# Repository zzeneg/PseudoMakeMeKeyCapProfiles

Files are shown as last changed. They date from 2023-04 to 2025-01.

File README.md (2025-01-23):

# Pseudo Make Me Key Cap Profile

## Added by zzeneg

#### DES MX

Compatible with **KS-33** (Gateron Lop Profile), **Choc V2**, **MX** and **mid-MX** (Tecsee Medium)

- [low profile version](./stl/MX-LP) - shorter skirt for low profile compatibility
- [minY minZ version](./stl/MX-minY-minZ) - 19x16mm spacing and reduced height, additional keycaps for edges (tilted inside)

#### DES Choc v1

- [minY version](./stl/Choc-minY) - 19x16mm spacing, additional keycaps for edges (tilted inside)

> [!WARNING]
> All versions are tested in MJF Nylon from JLCPCB only, be careful with other materials/manufacturers, make a small test order if possible.

## What the fork

- scripts to generate CS, DES, and Liminal Chimera keycaps
- sprued stls packs for MJF/SLS printing
- adding 1.25 to 2.25u Choc CS regular and convex caps

## How to

- make sure OpenSCAD is up to date.
- unzip libraries.zip into your OpenSCAD libraries
- select keycap you want to render by changing KeyID value
- change KeyID to corresponding Parameter ID
- press F5 to review
- press F6 to render
- press F7 to export as STL

#Some notes on

## Distorted Ellipsoidal Saddle (DES)

High sculpt smooth transition profile
DES

### Standard

Neuron v1

### Concave

Corne thumb and Convex Caps

### Thumbs

IMK Corne v1
Kyria

### Chicago Stenographer

Subtly sculpted choc spaced low profile
CS

#### Standard

Look

#### Convex

Georgi

#### Thumbs

1.5 + 1
Additional sculpt angle and smoother transitions

### Philadelphia Minimalist

under
Minimal spacing
Under construction

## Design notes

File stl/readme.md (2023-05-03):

Note
======

### Chicago Steno
- 1u sets have been printed in MJF by JLCPCB once with excellent results.
- thumbs are asymmetrical. Each set contains three pairs.
- 1.25~2.25u keys were modified by me and have not tested

### DES, Liminal Chimera
* MX stems are generated with `Tol=0.0`, tested once with good results in SLS. Not sure about resin.

Proceed with caution.

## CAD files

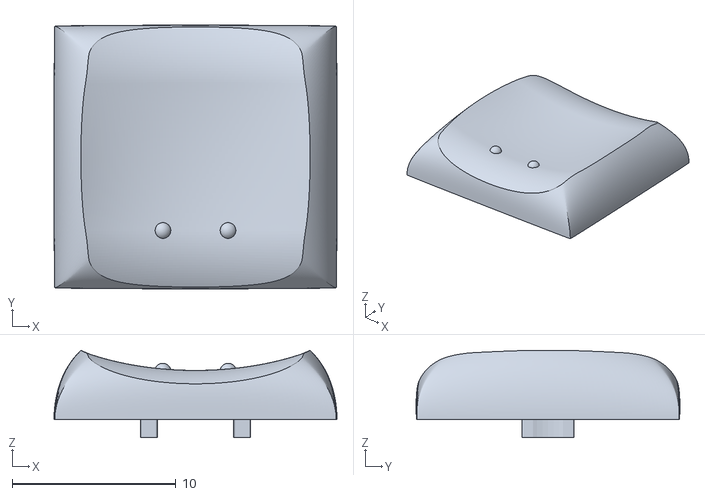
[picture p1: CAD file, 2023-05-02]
stl/Choc/Chicago_Steno_R3_homedot.stl
17.3 x 16.1 x 5.35

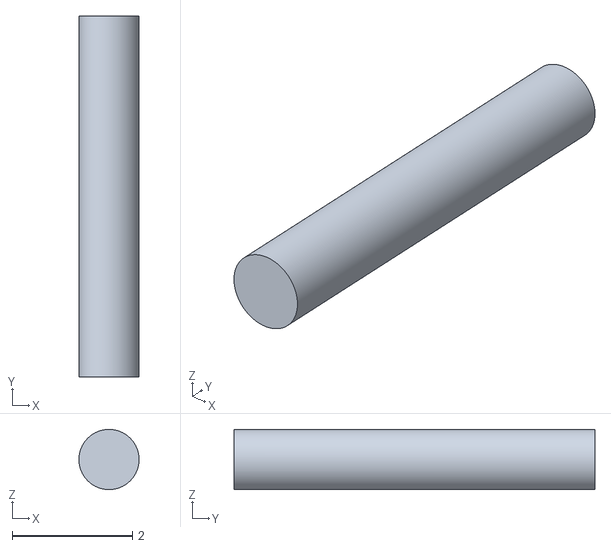
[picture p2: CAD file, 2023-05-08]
stl/MX/DES_r5_convex_1.50u_x2.stl
1.00 x 6.00 x 1.00

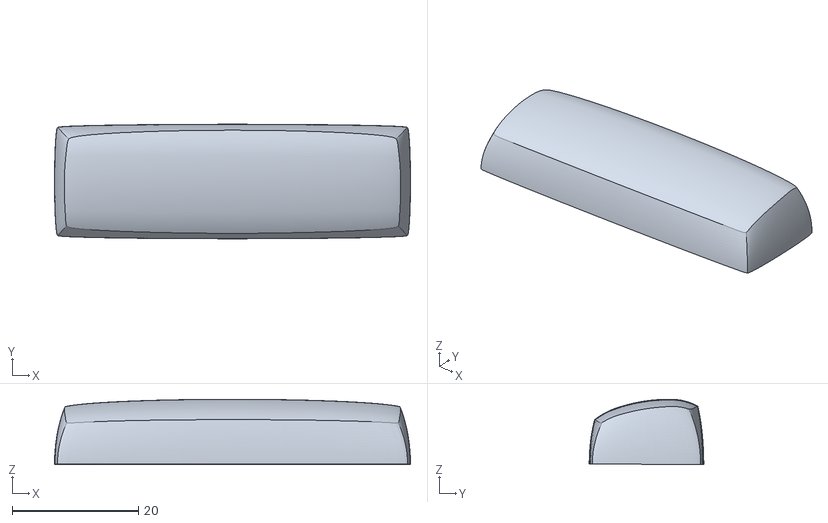
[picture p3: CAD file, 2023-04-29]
stl/MX/DES_r5_convex_3u.stl
56.3 x 18.1 x 10.4

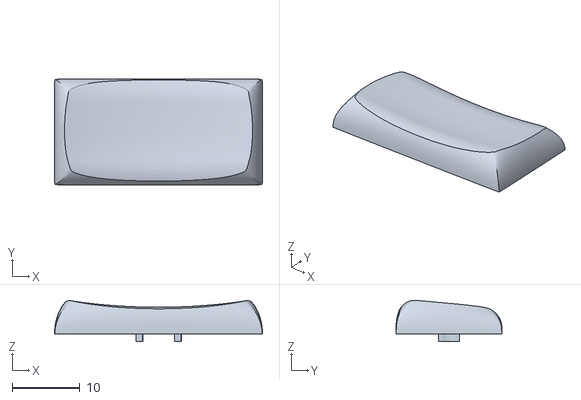
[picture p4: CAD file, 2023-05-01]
stl/Choc/Chicago_Steno_R2_1.75u.stl
30.8 x 15.7 x 6.08

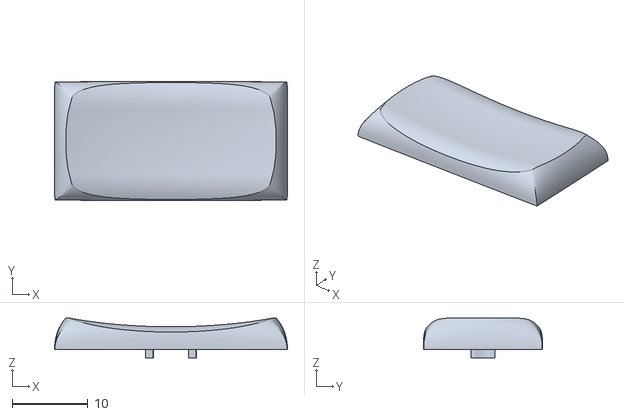
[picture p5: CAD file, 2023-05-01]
stl/Choc/Chicago_Steno_R3_1.75u.stl
30.8 x 15.7 x 5.26

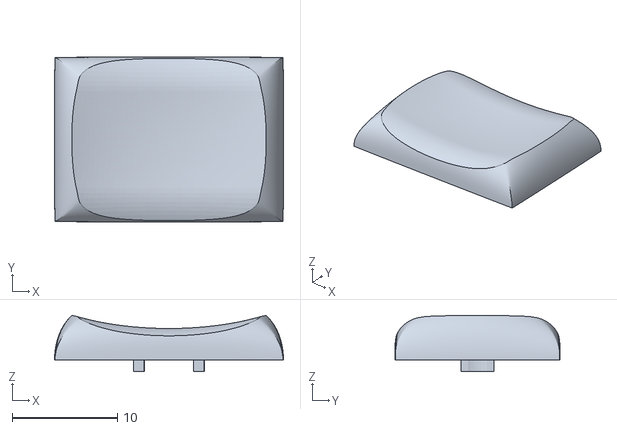
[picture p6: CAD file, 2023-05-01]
stl/Choc/Chicago_Steno_R3_1.25u.stl
21.8 x 15.7 x 5.37

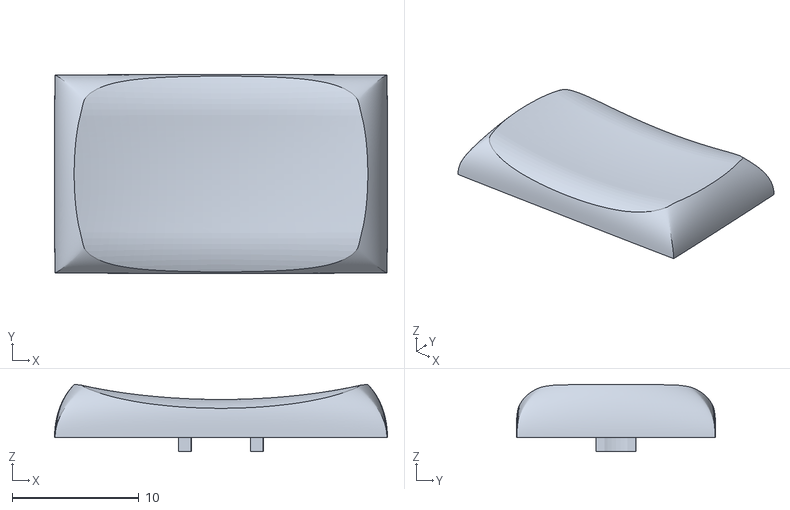
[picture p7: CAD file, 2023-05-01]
stl/Choc/Chicago_Steno_R3_1.50u.stl
26.3 x 15.7 x 5.30

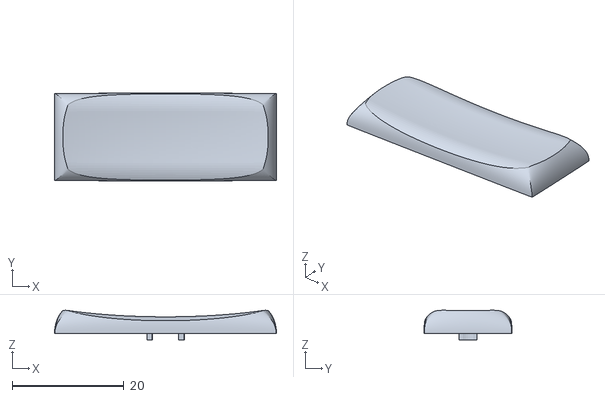
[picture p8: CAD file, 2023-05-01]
stl/Choc/Chicago_Steno_R3_2.25u.stl
39.8 x 15.7 x 5.30

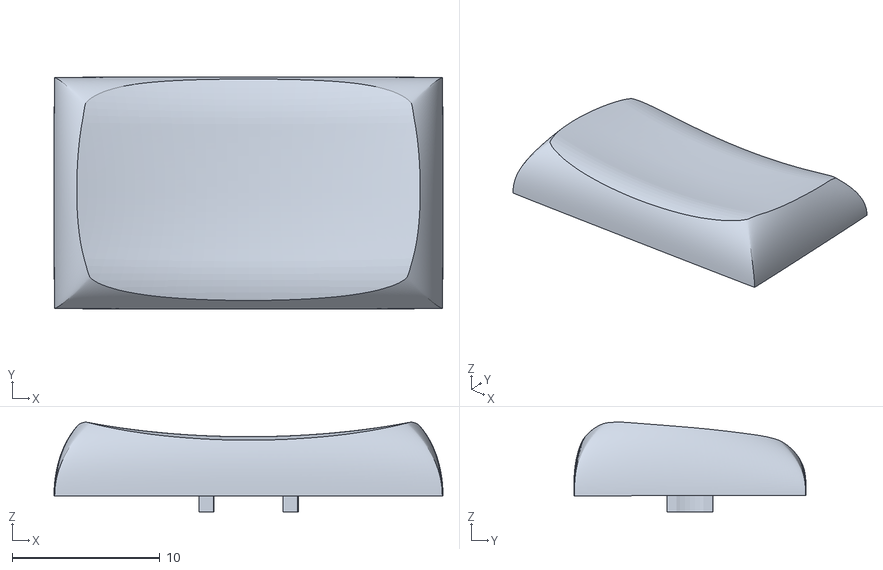
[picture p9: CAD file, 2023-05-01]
stl/Choc/Chicago_Steno_R2_1.50u.stl
26.3 x 15.7 x 6.07

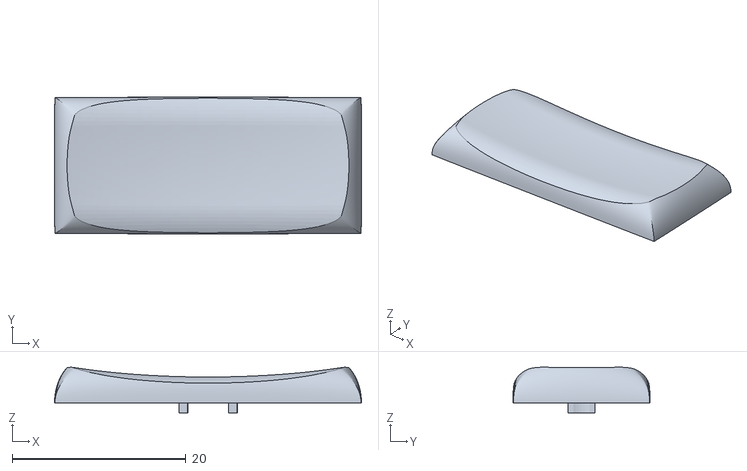
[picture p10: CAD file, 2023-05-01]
stl/Choc/Chicago_Steno_R3_2.00u.stl
35.3 x 15.7 x 5.25

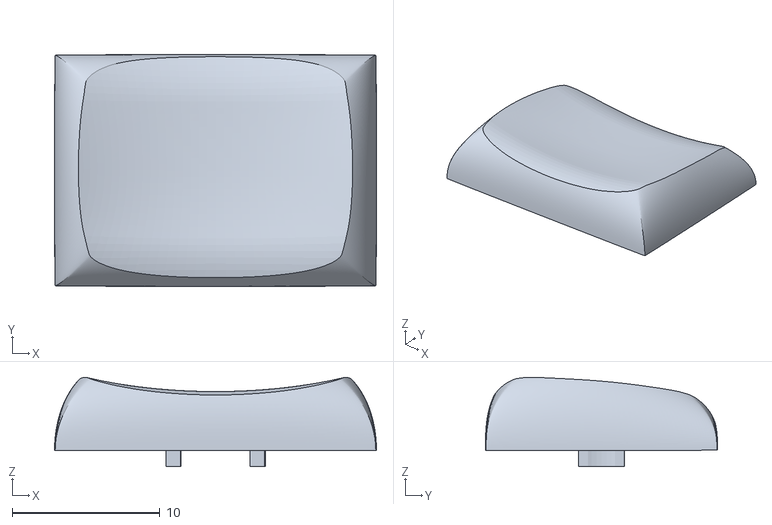
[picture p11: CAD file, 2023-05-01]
stl/Choc/Chicago_Steno_R2_1.25u.stl
21.8 x 15.7 x 6.05

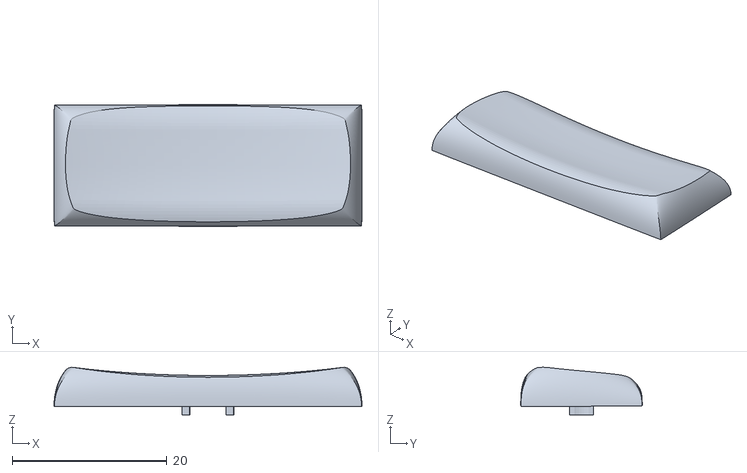
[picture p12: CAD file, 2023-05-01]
stl/Choc/Chicago_Steno_R2_2.25u.stl
39.8 x 15.7 x 6.15

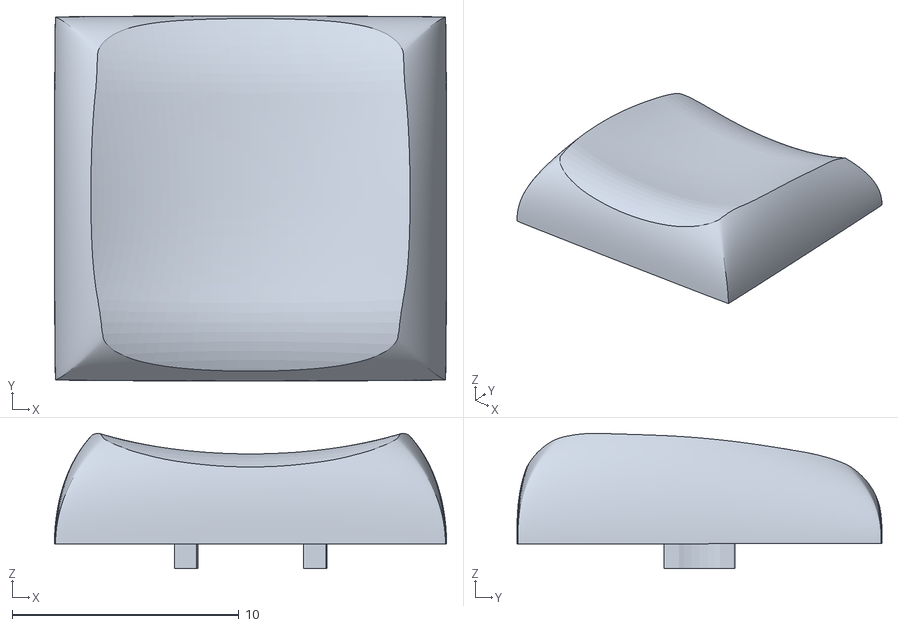
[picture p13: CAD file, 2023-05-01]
stl/Choc/Chicago_Steno_R2_1.00u.stl
17.3 x 16.1 x 5.97

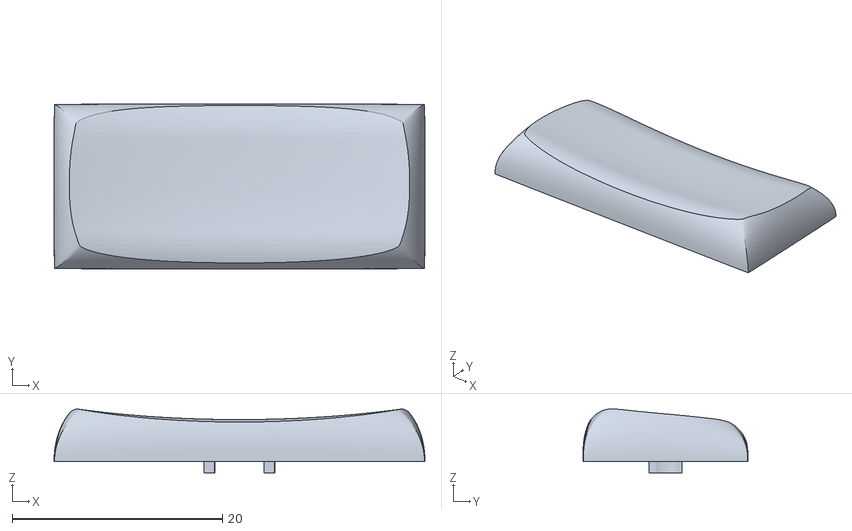
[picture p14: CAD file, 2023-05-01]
stl/Choc/Chicago_Steno_R2_2.00u.stl
35.3 x 15.7 x 6.09

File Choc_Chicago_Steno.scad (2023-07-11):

use <./libraries/scad-utils/morphology.scad> //for cheaper minwoski
use <./libraries/scad-utils/transformations.scad>
use <./libraries/scad-utils/shapes.scad>
use <./libraries/scad-utils/trajectory.scad>
use <./libraries/scad-utils/trajectory_path.scad>
use <./libraries/sweep.scad>
use <./libraries/skin.scad>
//use <z-butt.scad>

//Choc Chord version Chicago Stenographer

/*Tester */
keycap(
  keyID  = 6, //change profile refer to KeyParameters Struct
  cutLen = 0, //Don't change. for chopped caps
  Stem   = true, //tusn on shell and stems
  StemRot = 0, //change stem orientation by deg
  Dish   = true, //turn on dish cut
  Stab   = 0,
  visualizeDish = false, // turn on debug visual of Dish
  crossSection  = false, // center cut to check internal
  homeDot = false, //turn on homedots,
  homeBar = true, //turn on homebar,
  Legends = false
  );

//-Parameters
wallthickness = 1.1; // 1.75 for mx size, 1.1
topthickness = 3.0; //2 for phat 3 for chicago
stepsize = 50;  //resolution of Trajectory
step = 0.5;       //resolution of ellipes
fn = 60;          //resolution of Rounded Rectangles: 60 for output
layers = 50;    //resolution of vertical Sweep: 50 for output

//---Stem param
slop    = 0.3;
stemRot = 0;
stemWid = 8;
stemLen = 6;
stemCrossHeight = 1.8;
extra_vertical = 0.6;
stemLayers = 50; //resolution of stem to cap top transition
//#cube([18.16, 18.16, 10], center = true); // sanity check border

//injection param
draftAngle = 0; //degree  note:Stem Only
//TODO: Add wall thickness transition?


keyParameters = //keyParameters[KeyID][ParameterID]
[
//  BotWid, BotLen, TWDif, TLDif, keyh, WSft, LSft  XSkew, YSkew, ZSkew, WEx, LEx, CapR0i, CapR0f, CapR1i, CapR1f, CapREx, StemEx
    //Column 0
    //Levee: Chicago in choc Dimension
    [17.20,  16.00,   5.6, 	   5,  4.9,    0,   .0,     5,    -0,    -0,   2, 2.5,    .10,      2,     .10,      3,     2,       2], //Chicago Steno R2/R4
    [17.20,  16.00,   5.6, 	   5,  4.5,    0,   .0,     0,    -0,    -0,   2, 2.5,    .10,      3,     .10,      3,     2,       2], //Chicago Steno R3 flat
    [17.20,  16.00,  1.25, 	1.25,  4.5,    0,   .0,     0,    -0,    -0,   2, 2.5,    .10,     .5,     .10,     .5,     2,       2], //Chicago Steno R3 chord
    //mods 3
    [17.20,  16.00,  4.25, 	3.25,  5.5,  -.7,  0.7,     0,    -4,    -0,   2,   2,    .10,      2,     .10,      2,     2,       2], //Levee Corner R2
    [17.20,  16.00,  4.25, 	3.25,  5.2,  -.8,  0.6,     0,    -4,    -0,   2,   3,    .10,      2,     .10,      2,     2,       2], //Levee Corner R2
    //1.25: [5, 6]
    [21.7,   15.60,  5.6, 	   5,  4.9,    0,   .0,     5,    -0,    -0,   2, 2.5,     .1,      2,      .1,      3,     2,       2], //Chicago Steno R2/R4 1.25u
    [21.7,   15.60,  5.6, 	   5,  4.5,    0,   .0,     0,    -0,    -0,   2, 2.5,     .1,      3,      .1,      3,     2,       2], //Chicago Steno R3 1.25u
    //1.5: [7, 8]
    [26.20,  15.60,   5.6, 	   5,  4.9,    0,   .0,     5,    -0,    -0,   2, 2.5,     .1,      2,      .1,      3,     2,       2], //Chicago Steno R2/R4 1.5
    [26.20,  15.60,   5.6, 	   5,  4.5,    0,   .0,     0,    -0,    -0,   2, 2.5,     .1,      3,      .1,      3,     2,       2], //Chicago Steno R3 1.5u
    //1.75: [9, 10]
    [30.70,  15.60,   5.6, 	   5,  4.9,    0,   .0,     5,    -0,    -0,   2, 2.5,     .1,      2,      .1,      3,     2,       2], //Chicago Steno R2/R4 1.5
    [30.70,  15.60,   5.6, 	   5,  4.5,    0,   .0,     0,    -0,    -0,   2, 2.5,     .1,      3,      .1,      3,     2,       2], //Chicago Steno R3 1.5u
    //2.00: [11, 12]
    [35.20,  15.60,   5.6, 	   5,  4.9,    0,   .0,     5,    -0,    -0,   2, 2.5,     .1,      2,      .1,      3,     2,       2], //Chicago Steno R2/R4 1.5
    [35.20,  15.60,   5.6, 	   5,  4.5,    0,   .0,     0,    -0,    -0,   2, 2.5,     .1,      3,      .1,      3,     2,       2], //Chicago Steno R3 1.5u
    //2.25: [13, 14]
    [39.70,  15.60,   5.6, 	   5,  4.9,    0,   .0,     5,    -0,    -0,   2, 2.5,     .1,      2,      .1,      3,     2,       2], //Chicago Steno R2/R4 1.5
    [39.70,  15.60,   5.6, 	   5,  4.5,    0,   .0,     0,    -0,    -0,   2, 2.5,     .1,      3,      .1,      3,     2,       2], //Chicago Steno R3 1.5u
    // Ergo shits
    [18.75,  18.75,   5.6, 	   5,    8,    0,   .25,     0,    -0,    -0,   2, 2.5,    .10,      3,     .10,      3,     2,       2], //highpro 19.05 R2|4
    [17.20,  16.00,   5.6, 	   5,  4.7,    0,   .0,      3,    -0,    -0,   2, 2.5,    .10,      2,     .10,      3,     2,       2], //Chicago Steno R2 ALT
    [17.20,  16.00,   5.6, 	   5,  5.5,    0,   .0,      7,    -0,    -0,   2, 2.5,    .10,      2,     .10,      3,     2,       2], //Chicago Steno R1 Steap
    [17.20,  16.00,   5.6, 	   5,  7.0,    0,   .0,     10,    -0,    -0,   2, 2.5,    .10,      2,     .10,      3,     2,       2] //Chicago Steno R1 mild with alt R2
];

dishParameters = //dishParameter[keyID][ParameterID]
[
//FFwd1 FFwd2 FPit1 FPit2  DshDep DshHDif FArcIn FArcFn FArcEx     BFwd1 BFwd2 BPit1 BPit2  BArcIn BArcFn BArcEx
  //Column 0
  [ 4.5,    4,    7,  -50,      7,    1.7,   11.5,    17.5,     2,      4.5,    4,    2,   -35,   11.5,  15,     2], //Chicago Steno R2/R4
  [ 4.5,    4,    5,  -40,      7,    1.7,   11.5,    15,     2,      4.5,    4,    5,   -40,   11.5,    15,     2], //Chicago Steno R3 flat
  [ 4.5,    4,    5,  -40,      7,    1.7,   11.5,    15,     2,      4.5,    4,    5,   -40,   11.5,    15,     2], //Chicago Steno R3 chord

  [   6,  3.5,    7,  -50,      5,    1.0,   16,    23,     2,        6,  3.5,    7,   -50,   16,    23,     2], //Levee Steno R2/R4
  [   6,  3.5,    7,  -50,      5,    1.0,   16,    23,     2,        6,  3.5,    7,   -50,   16,    23,     2], //Levee Steno R2/R4
  //1.25
  [ 4.5,    4,    7,  -40,      8,    1.7,   16.0,  22.5,     2,      4.5,    4,    2,   -35,   16.0,  19.5,     2], //Chicago Steno R2/R4
  [ 4.5,    4,    5,  -40,      8,    1.7,   16.0,  19.5,     2,      4.5,    4,    5,   -40,   16.0,  19.5,     2], //Chicago Steno R3
  //1.5
  [ 4.5,    4,    7,  -40,      8,    1.7,   20.5,  26.5,     2,      4.5,    4,    2,   -35,   20.5,  24.0,     2], //Chicago Steno R2/R4
  [ 4.5,    4,    5,  -40,      8,    1.7,   20.5,  24.0,     2,      4.5,    4,    5,   -40,   20.5,  24.0,     2], //Chicago Steno R3
  //1.75
  [ 4.5,    4,    7,  -40,      8,    1.7,   25.0,  31.0,     2,      4.5,    4,    2,   -35,   25.0,  28.5,     2], //Chicago Steno R2/R4
  [ 4.5,    4,    5,  -40,      8,    1.7,   25.0,  28.5,     2,      4.5,    4,    5,   -40,   25.0,  28.5,     2], //Chicago Steno R3
  //2.00
  [ 4.5,    4,    7,  -40,      8,    1.7,   29.5,  35.5,     2,      4.5,    4,    2,   -35,   29.5,  33.0,     2], //Chicago Steno R2/R4
  [ 4.5,    4,    5,  -40,      8,    1.7,   29.5,  33.0,     2,      4.5,    4,    5,   -40,   29.5,  33.0,     2], //Chicago Steno R3
  //2.25
  [ 4.5,    4,    7,  -40,      8,    1.7,   33.0,  39.0,     2,      4.5,    4,    2,   -35,   33.0,  36.5,     2], //Chicago Steno R2/R4
  [ 4.5,    4,    5,  -40,      8,    1.7,   33.0,  36.5,     2,      4.5,    4,    5,   -40,   33.0,  36.5,     2], //Chicago Steno R3

  [   5,    5,    5,  -40,      7,    1.7,   11,    15,     2,        5,    5,    5,   -40,   11,    15,     2], //Chicago Steno R3 flat
  [ 4.5,    4,    7,  -50,      7,    1.7,   11,    17,     2,      4.5,    4,    2,   -35,   11,    15,     2], //Chicago Steno R1
  [ 4.5,    4,    7,  -50,      7,    1.7,   11,    17,     2,      4.5,    4,    2,   -35,   11,    15,     2], //Chicago Steno R1
  [ 4.5,    4,    7,  -50,      7,    1.7,   11,    17,     2,      4.5,    4,    2,   -35,   11,    15,     2] //Chicago Steno R1
];


function BottomWidth(keyID)  = keyParameters[keyID][0];  //
function BottomLength(keyID) = keyParameters[keyID][1];  //
function TopWidthDiff(keyID) = keyParameters[keyID][2];  //
function TopLenDiff(keyID)   = keyParameters[keyID][3];  //
function KeyHeight(keyID)    = keyParameters[keyID][4];  //
function TopWidShift(keyID)  = keyParameters[keyID][5];
function TopLenShift(keyID)  = keyParameters[keyID][6];
function XAngleSkew(keyID)   = keyParameters[keyID][7];
function YAngleSkew(keyID)   = keyParameters[keyID][8];
function ZAngleSkew(keyID)   = keyParameters[keyID][9];
function WidExponent(keyID)  = keyParameters[keyID][10];
function LenExponent(keyID)  = keyParameters[keyID][11];
function CapRound0i(keyID)   = keyParameters[keyID][12];
function CapRound0f(keyID)   = keyParameters[keyID][13];
function CapRound1i(keyID)   = keyParameters[keyID][14];
function CapRound1f(keyID)   = keyParameters[keyID][15];
function ChamExponent(keyID) = keyParameters[keyID][16];
function StemExponent(keyID) = keyParameters[keyID][17];
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

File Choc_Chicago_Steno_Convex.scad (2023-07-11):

use <./libraries/scad-utils/morphology.scad> //for cheaper minwoski
use <./libraries/scad-utils/transformations.scad>
use <./libraries/scad-utils/shapes.scad>
use <./libraries/scad-utils/trajectory.scad>
use <./libraries/scad-utils/trajectory_path.scad>
use <./libraries/sweep.scad>
use <./libraries/skin.scad>
//use <z-butt.scad>

//NOTE: with sweep cuts, top surface may not be visible in review, it should be visible once rendered

mirror([0,0,0])keycap(
  keyID  = 2, //change profile refer to KeyParameters Struct
  cutLen = 0, //Don't change. for chopped caps
  Stem   = true, //tusn on shell and stems
  StemRot = 0,//change stem orientation by deg
  Dish   = true, //turn on dish cut
  Stab   = 0,
  visualizeDish = true, // turn on debug visual of Dish
  crossSection  = false, // center cut to check internal
  homeDot = false, //turn on homedots
  Legends = false
);

//Parameters
wallthickness = 1.2;
topthickness  = 2;   //
stepsize      = 50;  //resolution of Trajectory
step          = 1;   //resolution of ellipes
fn            = 60;  //resolution of Rounded Rectangles: 60 for output
layers        = 50;  //resolution of vertical Sweep: 50 for output
dotRadius     = 1.25;   //home dot size
//---Stem param
slop    = 0.25;
stemWid = 8;
stemLen = 6;
stemCrossHeight = 1.8;
extra_vertical  = 0.6;
StemBrimDep     = 0;
stemLayers      = 50; //resolution of stem to cap top transition
driftAngle      = 0;

keyParameters = //keyParameters[KeyID][ParameterID]
[
//  BotWid, BotLen, TWDif, TLDif, keyh, WSft, LSft  XSkew, YSkew, ZSkew, WEx, LEx, CapR0i, CapR0f, CapR1i, CapR1f, CapREx, StemEx
    //Column 0
    //Levee: Chicago in choc Dimension 0-3
    [17.20,  16.00,   5.6, 	   5,  3.8,    0,  -.5,     7,    -0,    -0,   2, 2,    .10,      3,     .10,      3,     2,       2], //Chicago Steno R2x 1u
    [17.20,  16.00,   5.6, 	   5,  4.4,    0,   .0,     0,    -0,    -0,   2, 2,    .10,      3,     .10,      3,     2,       2], //Chicago Steno R3x 1u

    // R3x 1.25~2.25u [4:8]
    [21.7,   15.60,   5.6, 	   5.6,  4.5,   0,   .0,   0,    -0,    -0,   2, 2.5,   .1,      3,     .1,      3,     2,       2], //Chicago Steno R3x 1.25u
    [26.20,  15.60,   5.6, 	   5.6,  4.5,   0,   .0,   0,    -0,    -0,   2, 2.5,   .1,      3,     .1,      3,     2,       2], //Chicago Steno R3x 1.5u
    [30.70,  15.60,   5.6, 	   5.6,  4.5,   0,   .0,   0,    -0,    -0,   2, 2.5,   .1,      3,     .1,      3,     2,       2], //Chicago Steno R3x 1.75u
    [35.20,  15.60,   5.6, 	   5.6,  4.5,   0,   .0,   0,    -0,    -0,   2, 2.5,   .1,      3,     .1,      3,     2,       2], //Chicago Steno R3x 2.0u
    [39.70,  15.60,   5.6, 	   5.6,  4.5,   0,   .0,   0,    -0,    -0,   2, 2.5,   .1,      3,     .1,      3,     2,       2], //Chicago Steno R3x 2.25u

//  original from pseudo, mislabled/ missing params?
//    [35.85,  15.65,     7, 	   7,  4.4,    0,   .0,     0,    -0,    -0,   2, 2,    .30,      5,     .30,      5,     2,       2], //Chicago Steno R3x 2u
//    [35.85,  15.65,     7, 	   7,  4.4,    0,   .0,     0,    -0,    -0,   2, 2,    .30,      5,     .30,      5,     2,       2], //Chicago Steno R3x 2u
//    //mods 3
//    [17.20,  16.00,  4.25, 	3.25,  5.5,  -.7,  0.7,     0,    -4,    -0,   2,   2,    .10,      2,     .10,      2,     2,       2], //Levee Corner R2
//    [17.20,  16.00,  4.25, 	3.25,  5.2,  -.8,  0.6,     0,    -4,    -0,   2,   3,    .10,      2,     .10,      2,     2,       2], //Levee Corner R2
//    //1.25 5
//    [21.3,   15.60,  5.6, 	   5,  4.5,    0,   .0,     5,    -0,    -0,   2,   2,     .5,      3,      .5,      3,     2,       2], //Chicago Steno R2/R4 1.25u
//    [21.4,   15.60,  5.6, 	   5,  4.5,    0,   .0,     0,    -0,    -0,   2,   2,     .5,      3,      .5,      3,     2,       2], //Chicago Steno R3 1.25u
//    //1.5 7
//    [26.15,  15.60,   5.6, 	   5,  4.5,    0,   .0,     5,    -0,    -0,   2,   2,     .5,      3,      .5,      3,     2,       2], //Chicago Steno R2/R4 1.5
//    [26.15,  15.60,   5.6, 	   5,  4.5,    0,   .0,     0,    -0,    -0,   2,   2,     .5,      3,      .5,      3,     2,       2], //Chicago Steno R3 1.5u
//    //1.75 9
//    [30.90,  15.60,   5.6, 	   5,  4.5,    0,   .0,     5,    -0,    -0,   2,   2,     .5,      3,      .5,      3,     2,       2], //Chicago Steno R2/R4 1.5
//    [30.90,  15.60,   5.6, 	   5,  4.5,    0,   .0,     0,    -0,    -0,   2,   2,     .5,      3,      .5,      3,     2,       2], //Chicago Steno R3 1.5u
//    // Ergo shits
//    [18.75,  18.75,   5.6, 	   5,    8,    0,   .25,     0,    -0,    -0,   2, 2.5,    .10,      3,     .10,      3,     2,       2], //highpro 19.05 R2|4
//    [17.20,  16.00,   5.6, 	   5,  4.7,    0,   .0,      3,    -0,    -0,   2, 2.5,    .10,      2,     .10,      3,     2,       2], //Chicago Steno R2 ALT
//    [17.20,  16.00,   5.6, 	   5,  5.5,    0,   .0,      7,    -0,    -0,   2, 2.5,    .10,      2,     .10,      3,     2,       2], //Chicago Steno R1 Steap
//    [17.20,  16.00,   5.6, 	   5,  7.0,    0,   .0,     10,    -0,    -0,   2, 2.5,    .10,      2,     .10,      3,     2,       2], //Chicago Steno R1 mild with alt R2
];

dishParameters = //dishParameter[keyID][ParameterID]
[
//FFwd1 FFwd2 FPit1    FPit2  DshDepi    DshHDif FArcIn  FArcFn FArcEx  BFwd1 BFwd2 BPit1 BPit2  BArcIn BArcFn BArcEx
  [   5,  2.3,    2,     -55,    1.5,    3.75,     8.5,    8.5,    2,      5,    3,    2,  -50,    8.5,    8.7 ,     2], //R2x 1u
  [ 4.5,  3.3,   -3,     -45,    1.5,    3.75,     8.5,    8.7,    2,    4.5,  3.3,   -3,  -45,    8.5,   8.7,     2], //R3x 1u

  // R3x 1.25~2.25u [4:8]
  [ 4.5,  3.2,   -7,     -45,    1.5,    3.75,    10.75,   10.95,  2,    4.5,  3.2,   -7,  -45,   10.75,   10.95,  2], //R3x 1.25u
  [ 4.5,  3.2,   -7,     -45,    1.5,    3.75,    13.00,   13.20,  2,    4.5,  3.2,   -7,  -45,   13.00,   13.20,  2], //R3x 1.5u
  [ 4.5,  3.2,   -7,     -45,    1.5,    3.75,    15.25,   15.45,  2,    4.5,  3.2,   -7,  -45,   15.25,   15.45,  2], //R3x 1.75u
  [ 4.5,  3.2,   -7,     -45,    1.5,    3.75,    17.50,   17.70,  2,    4.5,  3.2,   -7,  -45,   17.50,   17.70,  2], //R3x 2.00u
  [ 4.5,  3.2,   -7,     -45,    1.5,    3.75,    19.75,   19.95,  2,    4.5,  3.2,   -7,  -45,   19.75,   19.95,  2], //R3x 2.25u

//  original from pseudo, mislabled/ missing params?
//  [ 4.5,  3.2,   -5,  -45,    1.5,   3.75,  19.0,    18,     2,     4.5,  3.2,   -5,  -45,   19.0,    18,     2], //R3x 2u
//  [ 4.5,  3.2,   -5,  -45,    1.5,   3.75,  19.0,    18,     2,     4.5,  3.2,   -5,  -45,   19.0,    18,     2], //R3x 2u
//  ---
//  [   4,  4.2,   -5,  -15,      1,      3,  18.2,    21,     2,       5,    3,   -5,  -15,   18.2,    21,     2], //R3 2u
//  [  4.,  1.5,    8,  -55,      3,      7,   9.0,     9,     2,       4,    3,    3,  -50,    9,     9,     2],  //R3
//  [  4.,  1.5,   -0,  -50,      3,      7,   9.0,     9,     2,       4,    3,    -10,  -50,    9,     9,     2],  //R3
//  [   5,  3.5,    8,  -50,      5,    1.8,   8.8,    15,     2,       6,    4,   13,   30,    8.8,    16,     2], //R1
];

function FrontForward1(keyID) = dishParameters[keyID][0];  //
function FrontForward2(keyID) = dishParameters[keyID][1];  //
function FrontPitch1(keyID)   = dishParameters[keyID][2];  //
function FrontPitch2(keyID)   = dishParameters[keyID][3];  //
function DishDepth(keyID)     = dishParameters[keyID][4];  //
function DishHeightDif(keyID) = dishParameters[keyID][5];  //
function FrontInitArc(keyID)  = dishParameters[keyID][6];
function FrontFinArc(keyID)   = dishParameters[keyID][7];
function FrontArcExpo(keyID)  = dishParameters[keyID][8];
function BackForward1(keyID)  = dishParameters[keyID][9];  //
function BackForward2(keyID)  = dishParameters[keyID][10];  //
function BackPitch1(keyID)    = dishParameters[keyID][11];  //
function BackPitch2(keyID)    = dishParameters[keyID][12];  //
function BackInitArc(keyID)   = dishParameters[keyID][13];
function BackFinArc(keyID)    = dishParameters[keyID][14];
function BackArcExpo(keyID)   = dishParameters[keyID][15];
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

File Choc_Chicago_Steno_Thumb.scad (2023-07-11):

use <./libraries/scad-utils/morphology.scad> //for cheaper minwoski
use <./libraries/scad-utils/transformations.scad>
use <./libraries/scad-utils/shapes.scad>
use <./libraries/scad-utils/trajectory.scad>
use <./libraries/scad-utils/trajectory_path.scad>
use <./libraries/sweep.scad>
use <./libraries/skin.scad>
//use <z-butt.scad>
// Choc Chord version Chicago Stenographer with sculpte Thumb cluter
// change stemrot

mirror([1,0,0])keycap(
  keyID   = 1, //change profile refer to KeyParameters Struct
  cutLen  = 0, //Don't change. for chopped caps
  Stem    = true, //tusn on shell and stems
  StemRot = 0,//change stem orientation by deg
  Dish    = true, //turn on dish cut
  Stab    = 0,
  visualizeDish = false, // turn on debug visual of Dish
  crossSection  = false, // center cut to check internal
  homeDot = false, //turn on homedots
  Legends = false
);

//-Parameters
wallthickness = 1.1; // 1.75 for mx size, 1.1
topthickness = 2.5; //2 for phat 3 for chicago
stepsize = 40;  //resolution of Trajectory
step =2;       //resolution of ellipes
fn = 60;          //resolution of Rounded Rectangles: 60 for output
layers = 50;    //resolution of vertical Sweep: 50 for output

//---Stem param
slop    = 0.3;
stemWid = 8;
stemLen = 6;
stemCrossHeight = 1.8;
extra_vertical = 0.6;
stemLayers = 50; //resolution of stem to cap top transition
//#cube([18.16, 18.16, 10], center = true); // sanity check border

//injection param
draftAngle = 0; //degree  note:Stem Only
//TODO: Add wall thickness transition?

keyParameters = //keyParameters[KeyID][ParameterID]
[
//  BotWid, BotLen, TWDif, TLDif, keyh, WSft, LSft  XSkew, YSkew, ZSkew, WEx, LEx, CapR0i, CapR0f, CapR1i, CapR1f, CapREx, StemEx
    //Column 0
    //Levee: Chicago in choc Dimension for ref
    [17.20,  16.00,   5.6, 	   5,  5.0,    0,   .0,     5,    -0,    -0,   2, 2.5,    .10,      2,     .10,      3,     2,       2], //Levee Steno R2/R4
    [17.20,  16.00,   5.6, 	   5,  4.6,    0,   .0,     0,    -0,    -0,   2, 2.5,    .10,      3,     .10,      3,     2,       2], //Levee Steno R3
    //Thumb
    [17.20,  16.00,  4.25, 	3.25,  5.0,  -.5,  0.0,    -3,    -3,    -0,   2,   2,    .10,      2,     .10,      2,     2,       2], //Thumb 1
    [15.65,  26.4,   5.5, 	3.25,  4.9,  -.5,  0.0,    -3,    -2,    -2,   2,   2,     .3,      2,      .3,    2.5,     2,       2], //Thumb 1.5
    [15.65,  35.8,  4.25, 	3.25,  4.9, -.25,  0.0,    -2.5,    -4,    -2,   2,   3,     .3,      2,      .3,    2.5,     2,       2], //Thumb 2.0
    //1.25 5
    [21.3,   15.60,  5.6, 	   5,  4.5,    0,   .0,     5,    -0,    -0,   2,   2,     .5,      3,      .5,      3,     2,       2], //Chicago Steno R2/R4 1.25u
    [21.4,   15.60,  5.6, 	   5,  4.5,    0,   .0,     0,    -0,    -0,   2,   2,     .5,      3,      .5,      3,     2,       2], //Chicago Steno R3 1.25u
    //1.5 7
    [26.15,  15.60,   5.6, 	   5,  4.5,    0,   .0,     5,    -0,    -0,   2,   2,     .5,      3,      .5,      3,     2,       2], //Chicago Steno R2/R4 1.5
    [26.15,  15.60,   5.6, 	   5,  4.5,    0,   .0,     0,    -0,    -0,   2,   2,     .5,      3,      .5,      3,     2,       2], //Chicago Steno R3 1.5u
    //1.75 9
    [30.90,  15.60,   5.6, 	   5,  4.5,    0,   .0,     5,    -0,    -0,   2,   2,     .5,      3,      .5,      3,     2,       2], //Chicago Steno R2/R4 1.5
    [30.90,  15.60,   5.6, 	   5,  4.5,    0,   .0,     0,    -0,    -0,   2,   2,     .5,      3,      .5,      3,     2,       2], //Chicago Steno R3 1.5u
    // Ergo shits
    [18.75,  18.75,   5.6, 	   5,    8,    0,   .25,     0,    -0,    -0,   2, 2.5,    .10,      3,     .10,      3,     2,       2], //highpro 19.05 R2|4
    [17.20,  16.00,   5.6, 	   5,  4.7,    0,   .0,      3,    -0,    -0,   2, 2.5,    .10,      2,     .10,      3,     2,       2], //Chicago Steno R2 ALT
    [17.20,  16.00,   5.6, 	   5,  5.5,    0,   .0,      7,    -0,    -0,   2, 2.5,    .10,      2,     .10,      3,     2,       2], //Chicago Steno R1 Steap
    [17.20,  16.00,   5.6, 	   5,  7.0,    0,   .0,     10,    -0,    -0,   2, 2.5,    .10,      2,     .10,      3,     2,       2], //Chicago Steno R1 mild with alt R2

];

dishParameters = //dishParameter[keyID][ParameterID]
[
//FFwd1 FFwd2 FPit1 FPit2  DshDep DshHDif FArcIn FArcFn FArcEx     BFwd1 BFwd2 BPit1 BPit2  BArcIn BArcFn BArcEx FTani FTanf BTani BTanf TanEX PhiInit PhiFin
  //Column 0
  [ 4.5,    4,    7,  -50,      7,    1.7,   11,    17,     2,      4.5,    4,    2,   -35,   11,    15,     2,     3,  4.5,    3,  4.5,   2, 203, 210], //Chicago Steno R2/R4
  [ 4.5,    4,    5,  -40,      7,    1.7,   11,    15,     2,      4.5,    4,    5,   -40,   11,    15,     2,     4,    5,    4,    5,   2, 200, 210], //Chicago Steno R3 flat

  [   5,  5.5,    0,  -40,      7,    1.7,   16,    18,     2,       5.5,  3.5,    5,   -50,   16,    18,     2,     5,   3.75,    2,    3.75,   2, 199, 210], //T1
  [  10,  4.5,    0,  -40,      7,    1.7,   16,    15,     2,        10,  3.5,    5,   -50,   16,    18,     2,     3,   3.75,    .75,    3.75,   2, 200, 210], //1.5u
  [  14.5, 4.5,   4,  -40,      7,    1.7,   16,    18,     2,      14.5,  4.5,    2,   -35,   16,    23,     2,     3,   3.75,    .75,    3.75,   2, 200, 210], //2.0u
  //1.25
  [ 4.5,    4,    7,  -40,      8,    1.8,   15,    20,     2,      4.5,    4,    2,   -35,   15,    20,     2,     3,    5,    7,    5,   2, 200, 210], //Chicago Steno R2/R4
  [ 4.5,    4,    5,  -40,      8,    1.8,   15,    20,     2,      4.5,    4,    5,   -40,   15,    20,     2,     3,    5,    7,    5,   2, 200, 210], //Chicago Steno R3
  //1.5
  [ 4.5,    4,    7,  -40,      8,    1.8,   19,    25,     2,      4.5,    4,    2,   -35,   19,    25,     2], //Chicago Steno R2/R4
  [ 4.5,    4,    5,  -40,      8,    1.8,   19,    25,     2,      4.5,    4,    5,   -40,   19,    25,     2], //Chicago Steno R3
  //1.75
  [ 4.5,    4,    7,  -40,      8,    1.8,   22.5,  27,     2,      4.5,    4,    2,   -35,   22.5,  27,     2], //Chicago Steno R2/R4
  [ 4.5,    4,    5,  -40,      8,    1.8,   22.5,  27,     2,      4.5,    4,    5,   -40,   22.5,  27,     2], //Chicago Steno R3
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

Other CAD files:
stl/Choc/Chicago_Steno_R3_homebar.stl
stl/Choc/Chicago_Steno_R3_1.00u.stl
stl/Choc/Chicago_Steno_R3_home.stl
stl/Choc/Chicago_Steno_Convex.stl
Choc_DES_minY.scad
LiminalChimera.scad
MX_Chicago_Steno.scad
MX_DES_Convex.scad
MX_DES_Standard-minY-minZ.scad
MX_DES_Standard.scad
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

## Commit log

2023-03-17 make homing dots convex
    [MX_DES_Standard.scad, spru.scad]
2023-03-17 output quality
    [Choc_Chicago_Steno.scad, Choc_Chicago_Steno_Convex.scad, Choc_Chicago_Steno_Thumb.scad]
2023-03-17 adding stls
    [Choc_Chicago_Steno_Convex.stl, Choc_Chicago_Steno_R2.stl, Choc_Chicago_Steno_R3.stl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]
2023-03-22 adding DES stls
    [des_r2_125u.stl, des_r2_150u.stl, des_r2_175u.stl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]
2023-04-04 adjusted stem tolerance for printing
    [MX_DES_Convex.scad, MX_DES_Standard.scad, MX_DES_Thumb.scad]
2023-04-04 remove bad stls
    [des_r1_num.stl, des_r2_125u.stl, des_r2_150u.stl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]
2023-04-20 adjust output resolution
    [MX_DES_Convex.scad, MX_DES_Standard.scad, MX_DES_Thumb.scad]
2023-04-20 add DES export scripts
    [export_des.scad, export_des_convex.scad, export_des_thumbs.scad]
2023-04-20 tolerance fixed DES stls
    [export_des.scad]
2023-04-25 adding stabilizer stem for 2u and longer keys
    [MX_DES_Convex.scad, MX_DES_Standard.scad]
2023-04-25 adding DES r3 homing keys and stabilizer stems
2023-04-25 adding deepdish homing to export script
    [export_des.scad]
2023-04-26 adding stab for 2u keys too
    [MX_DES_Convex.scad, MX_DES_Standard.scad]
2023-04-26 renaming stl
2023-04-26 adding Liminal Chimera scad file
    [LiminalChimera.scad]
2023-04-26 Organizing and adding Liminal Chimeras (brimless DES)
    - Updated docs
    - LiminalChimera.scad tweaked for exporting
    - STLs renamed, organized by MX/Choc
    - LiminalChimera STLs added
    [Chicago_Steno_Convex.stl, Chicago_Steno_R2.stl, Chicago_Steno_R3.stl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]
2023-04-29 adding DES 3u and 40s bar sets
    [DES_r5_convex_3u.stl, MX_DES_Convex.scad]
2023-05-01 r2 is working but r3 dish cut isn't
    [Choc_Chicago_Steno.scad, export_cs.scad]
2023-05-01 - added CS r3 and r2 1+u stls - CS script was fine but for some reason it doesn't export properly from command line.
    [Chicago_Steno_R3_1.25u_x2.stl, Chicago_Steno_R3_1.50u_x2.stl, Chicago_Steno_R3_1.75u_x2.stl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]
2023-05-01 change big CS stls to export quality
    [Choc_Chicago_Steno.scad]
2023-05-01 first draft for MX spaced CS
    [Choc_Chicago_Steno_Fat.scad, export_cs.scad, export_cs_convex.scad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]
2023-05-01 Adjusted MX spaced CS to use the 2-step dish. Should be more similar to Choc CS and have improved key separation feeling.
    [Choc_Chicago_Steno_Fat.scad, export_fat_cs.scad]
2023-05-01 rename fat CS to MX CS
    [MX_Chicago_Steno.scad, export_mxspaced_cs.scad]
2023-05-01 adjusted dish for wide CS
    [Choc_Chicago_Steno.scad]
2023-05-01 CS additions:
    - 1.25 ~ 2.25u Chicago Steno stls, regular and convex
    - experimental MX spaced CS r2/r2
    [Chicago_Steno_R2.stl, Chicago_Steno_R2_1.00u.stl, Chicago_Steno_R2_1.25u.stl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]
2023-05-02 adding homing bar option
    [Chicago_Steno_R3_homebar.stl, Chicago_Steno_R3_homedot.stl, Choc_Chicago_Steno.scad]
2023-05-02 homing ring for DES
    [MX_DES_Standard.scad, export_cs.scad]
2023-05-02 more stls
    [Choc_Chicago_Steno.scad, MX_DES_Standard.scad]
2023-05-03 added DES 4u bar
    [MX_DES_Convex.scad]
2023-05-08 more DES stl
    [DES_r5_convex_1.50u_x2.stl, export_des.scad]
2023-05-17 modularized stem and keywidth
    [MX_DES_Convex.scad]
2023-07-11 use local libraries
    [Choc_Chicago_Steno.scad, Choc_Chicago_Steno_Convex.scad, Choc_Chicago_Steno_Thumb.scad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]
2023-07-11 fix warnings
    [export_des.scad]
2023-07-11 update scripts for low profile
    [MX_DES_Standard.scad, MX_DES_Thumb.scad, export_des.scad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]
2023-07-11 even lower DES
    [MX_DES_Standard.scad, MX_DES_Thumb.scad]
2023-07-29 tight stem, improve thumbs
    [MX_DES_Thumb.scad]
2023-08-14 tight stem according to spec
    [MX_DES_Standard.scad, MX_DES_Thumb.scad]
2023-09-02 fix DES inner shape for KS-33 compatibility
    [MX_DES_Standard.scad, MX_DES_Thumb.scad, export_des.scad]
2024-02-19 add minY keycaps
    [MX_DES_Standard.scad, MX_DES_Thumb.scad, spru.scad]
2024-02-19 improve inner shape
    [MX_DES_Standard.scad, MX_DES_Thumb.scad]
2024-02-19 remove skirts
    [MX_DES_Standard.scad, MX_DES_Thumb.scad]
2024-03-16 more models
    [spru.scad]
2024-04-05 short versions
    [MX_DES_Standard.scad, MX_DES_Thumb.scad]
2024-04-20 fix minY-minZ thumbs
    [MX_DES_Thumb-minY-minZ.scad]
2024-07-13 add minY R3 edge
    [MX_DES_Standard-minY-minZ.scad, export_des.scad, spru.scad]
2024-11-02 test chocV2 compatibility
    [MX_DES_Standard-minY-minZ.scad, MX_DES_Thumb-minY-minZ.scad, spru.scad]
2024-11-21 add chocV2 compatibility for minY-minZ
    [export_des.scad, export_des_thumbs.scad, spru.scad]
2024-11-22 remove minY, update readme
    [MX_DES_Standard-minY.scad, MX_DES_Thumb-minY.scad]
2025-01-23 add DES choc minY
    [Choc_DES_minY.scad, export_des.scad, export_des_thumbs.scad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]
